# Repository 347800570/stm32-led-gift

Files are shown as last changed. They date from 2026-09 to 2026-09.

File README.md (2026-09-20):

# 基于STM32的灯带礼物制作项目

用木板、可寻址灯带和自己设计的控制板，制作一块能遥控、感知温度、跟随音乐闪动的灯牌。
采用 STM32F042G6U6TR + WS2812B，提供 KiCad 硬件、CubeMX/Keil 固件和基础实验。固件独立运行，不需要 Wi-Fi、手机应用或联网服务，也不是 WLED 固件移植版。

## 能做什么

| 遥控键 | 灯光效果 |
| --- | --- |
| 1 | 整条红橙黄绿蓝靛紫循环渐变 |
| 2 | 暖橙呼吸 |
| 3 | 沿灯珠编号流动的彩虹 |
| 4 | 蓝白流星 |
| 5 | 随机星光 |
| 6 | 根据实际位置，从木板底部向上燃烧的火焰 |
| 7 | 环境冷暖：18°C蓝、25°C绿、32°C红 |
| 8 | 根据声音大小，自下而上点亮的音量柱 |
| 9 | 检测鼓点能量突增，触发整条短暂闪光 |

POWER开关；+/-调整亮度；LEFT/RIGHT在1～7号调速度，在8/9号调声音灵敏度。
关灯时其他键不唤醒，也不修改设置。上电默认3号、15%亮度、速度和灵敏度均为第3档；调整只保存在RAM，断电恢复默认。

## 选择版本

| 固件 | 灯珠数 | 说明 |
| --- | --- | --- |
| [MPLT-67.hex](firmware/MPLT-67.hex) | 67 | 原始布局，27×8空间网格 |
| [SRKL-74.hex](firmware/SRKL-74.hex) | 74 | 新布局，33×12空间网格 |

74颗版本的9种模式已由作者上板验证正常。两套固件均在Windows上用ARMCC5重新编译并进行ARM指令仿真回归；仿真不验证实际电气时序。
首次发行 v0.1.0 为原型参考版本。硬件DRC仍有29项违规，不能把本仓库当作已完成生产审查的设计。

## 快速开始

1. 准备对应控制板、5V WS2812B灯带、NEC红外遥控器、5V电源及USB数据线或SWD下载器。
2. 将灯带DIN接到PB0对应的LED1_DATA，灯带和控制板共地，核对5V极性。
3. 用STM32CubeProgrammer下载对应HEX。SWD连接SWDIO、SWCLK、GND，必要时加NRST；USB DFU操作见[接线与烧录](docs/quick-start.md)。
4. 正常启动时BOOT0为低，复位后应出现彩虹。串口115200、8N1能看到READY日志。
5. 按遥控器1～9逐项验证。空间灯效要求实物排布匹配坐标文件；其他布局须重新编译。

电源按5V设计。Type-C接口并不意味着可以直接使用充电器标称的全部功率；供电能力取决于5V档、线缆、接口及布线。软件最高30%亮度不是闭环电流限制。

## 从哪里开始看

- [接线、下载和遥控使用](docs/quick-start.md)
- [编译、测试与移植布局](docs/development.md)
- [硬件状态与已知问题](docs/hardware.md)
- [基础实验导航](Software/Test/README.md)
- [67颗工程说明](Software/Official%20Version/MPLT_V03/README.md)
- [74颗工程说明](Software/Official%20Version/SRKL_V01/README.md)
- [原理图PDF](Hardware/LED_V01/Schematic.pdf)、[BOM](Hardware/LED_V01/BOM.csv)、[KiCad工程](Hardware/LED_V01/SCH-PCB/LED_V01.kicad_pro)
- [版本记录](CHANGELOG.md)、[贡献说明](CONTRIBUTING.md)、[第三方许可](THIRD_PARTY_NOTICES.md)

## 已知限制

- 使用同一套硬件引脚和指定NEC键码；其他遥控器需要重新学习键码。
- 声控是低频能量突增检测，不是音乐语义识别；拍桌也可能触发，部分音乐会漏检。
- 74颗版RAM静态分配5976/6144 B（含1024 B预留栈），继续增加灯珠或功能前必须重新核算。
- 温度仅用于显示环境冷暖，不承担过温保护。
- PCB为原型资料，DRC未通过；未发布可直接下单的Gerber附件。

## 许可

自有应用代码、测试和文档采用[MIT](LICENSE)；自有硬件设计采用[CERN-OHL-P-2.0](LICENSES/CERN-OHL-P-2.0.txt)。
STM32、CMSIS以及第三方元件库保留各自许可，以上授权不替代第三方许可，范围见[声明](THIRD_PARTY_NOTICES.md)。

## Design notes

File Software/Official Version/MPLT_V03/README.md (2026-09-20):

# MPLT V03：加入麦克风与两个声控模式

## 工程入口

- Keil 工程：`MDK-ARM/MPLT.uvprojx`，目标名 `MPLT`。
- 固件：`MDK-ARM/MPLT/MPLT.hex`；调试文件：`MDK-ARM/MPLT/MPLT.axf`。
- STM32F042G6U6TR，系统时钟 HSI48，48 MHz。
- PB0 / TIM3_CH3 / DMA1_Channel2 控制一条 67 颗 WS2812B 灯带。
- PA3 / EXTI 双边沿接收 NEC 红外，用户码字节为 `00 FF`。
- TIM14 自由运行，1 MHz，每 65.536 ms 回绕，不要在其他模块清零。
- USART1：PB6 TX、PB7 RX，115200、8N1，只输出日志。
- DS18B20：PA2 开漏、外部上拉、独立 VDD 供电；仅支持总线上一颗传感器，不使用寄生供电。
- 麦克风：PA0/ADC_IN0，TIM1 TRGO 8 kHz触发，DMA1_Channel1循环接收。
- 第二路灯带、PA1 实体按键保留基础配置，不启动业务。

## 操作规则

上电开灯，模式 3，亮度 15%，速度第 3 档，声音灵敏度第 3 档。

| 按键 | NEC 键码 | 功能 |
| --- | --- | --- |
| POWER | 0x45 | 开关灯，重新打开时恢复模式和参数 |
| 1 | 0x0C | 整条七色循环，默认保持 1 秒、渐变 1 秒 |
| 2 | 0x18 | 暖橙呼吸，默认一个周期 3 秒 |
| 3 | 0x5E | 流动彩虹，沿 1→67 方向移动 |
| 4 | 0x08 | 蓝白流星，沿 1→67 方向移动 |
| 5 | 0x1C | 暖白星光，随机位置淡入淡出 |
| 6 | 0x5A | 整板空间火焰，从木板底部向上升腾 |
| 7 | 0x42 | 环境温度颜色，18°C蓝、25°C绿、32°C红 |
| 8 | 0x52 | 空间音量柱，按实际高度从下往上点亮，绿→黄→红 |
| 9 | 0x4A | 低频鼓点触发整条闪光脉冲，颜色缓慢循环 |
| + | 0x40 | 增亮 3 个百分点，上限 30% |
| - | 0x19 | 减亮 3 个百分点，下限 3% |
| LEFT | 0x07 | 1～7号减速；8/9号降低声音灵敏度 |
| RIGHT | 0x09 | 1～7号加速；8/9号提高声音灵敏度 |

速度为 0.5、0.75、1、1.5、2 倍。数字键切换后重置动画。
POWER关闭时冻结动画，重新打开后继续；模式、亮度、速度、灵敏度均保留。
采样始终运行，重新打开声控模式时显示当前声音强弱。静音熄灭不等于POWER关机，仍可用数字键切模式。
关灯时所有非 POWER 按键均不改变状态，数字键也不能唤醒。
仅调整键支持长按：至少等待 350 ms，随后相邻调整至少间隔 160 ms；
实际间隔还取决于遥控器重复帧发送周期。POWER、模式键忽略 NEC 重复码。
重复帧距离上一个有效帧超过 180 ms 时不执行。
未分配键只输出提示。断电后全部恢复默认，不写 Flash。
温度模式的颜色只由温度决定，速度键仍改变全局速度设置，但不改变温度采样周期。

## V03 声控功能

### 数据流程

ADC硬件校准 → 启动128点循环DMA → 启动TIM1 → 每64点处理一次 → 去直流。
随后分两路：8号计算音量包络；9号提取低频能量并检测鼓点，触发独立灯光脉冲。

TIM1时钟48 MHz，PSC=47、ARR=124、TRGO=Update，采样周期125 us。
ADC为12位右对齐，DMA两端Half Word；独立缓冲128×2=256 B，每半缓冲64点对应8 ms。
ADC DMA回调只处理64点整数数据，不打印、不等待；红外中断优先级0，ADC DMA优先级1。
从已完成且DMA当前没有写入的半缓冲读取；处理前后核对DMA位置，发现过期数据就丢弃并恢复采样。

直流偏置由低通跟踪，时间常数约32 ms；初值取首个样本，以避免1.65V偏置造成虚假音量。
8号使用去直流后的平均绝对幅度，固定噪声门为 `Core/Inc/audio.h` 的 `AUDIO_NOISE_GATE=12`，不做上电背景噪声学习。
8号亮度每8 ms更新，上升向目标靠近一半，下降向目标靠近十六分之一，最终精确回到0。
9号采用低频能量突增检测，无FFT；不将8号包络或原始音量直接映射为亮度。

### 8号：空间音量柱

声音越大，点亮高度越高。四个字共同使用原来的y坐标，低处绿色、中间黄色、高处红色。
每个高度层独立使用亮灭滞回：超过原点亮阈值才点亮，已点亮后要降到更低的熄灭阈值才熄灭。
默认熄灭阈值比点亮阈值低一层音量跨度的25%；例如y=4层LEVEL达到128点亮，降到119及以下才熄灭。
120～127之间保持之前状态，同高度灯珠同步。临界层点亮后保留至少64/255的效果亮度，再统一乘全局亮度，避免RGB在零附近反复跳动。
亮度变化采用约80 ms满幅过渡；静音/采样故障的LEVEL=0会立即清空滞回状态并全黑，重新进入模式也重置状态。
参数位于 `Core/Inc/effects.h`：`VOLUME_HYSTERESIS_PERCENT`（默认25，允许1～99）、
`VOLUME_HOLD_BRIGHTNESS`（默认64）、`VOLUME_FADE_MS`（默认80）。若实物仍有边界闪烁，可适当增大滞回百分比。
整体仍受3%～30%的全局亮度设置限制。

### 9号：鼓点律动

全部67颗灯珠在检测到低频鼓点后立即达到固定效果峰值，再用150 ms线性渐灭。实际峰值仍受全局亮度限制。
每次触发后150 ms内不重复触发，两个鼓点之间的小幅音量波动不改变已触发的脉冲。
颜色保持12秒缓慢循环，LEFT/RIGHT调整鼓点触发难度，不改变色彩周期或单次脉冲峰值。

滤波器在8 kHz采样下使用一阶约40 Hz高通，串联两个一阶约400 Hz低通，同时保留更多中低频鼓声。
低通系数由37改为69；400 Hz指每个一阶环节，串联后的整体截止频率并非400 Hz，也不是理想带通边界。
能量先做短时平滑，再同时检查绝对门槛、相对近期背景能量的倍数以及能量明显上升。
触发后还要求能量回落再重新允许触发。背景以约256 ms时间尺度持续跟踪，采样启动前128 ms只建立滤波与背景状态。
切换模式清除尚未结束的闪光脉冲，检测器继续跟踪背景。采样故障立即全黑；恢复采样会重新建立背景状态。

参数在 `Core/Inc/beat.h`：`BEAT_REFRACTORY_MS`防重复间隔、`BEAT_PULSE_MS`渐灭时长，默认均为150。
`BEAT_HP_COEFF_Q8`、`BEAT_LP_COEFF_Q8`对应滤波系数，随采样率变化需重新设计。
旧的 `AUDIO_PULSE_RELEASE_DIVISOR` 已移除。
这是一种轻量能量突增检测，真实音乐仍需调试；拍桌、碰撞等低频冲击也可能触发，低频不明显的鼓声可能漏检。

### 灵敏度与噪声门

8/9号共用5档灵敏度，切模式保留、上电默认第3档。1～7号动画速度独立保存。
8号每档满量程交流幅度（已扣除噪声门）为320、200、128、80、48个ADC码值；数值越小越灵敏。
可在 `Core/Src/audio.c` 的 `full_scales` 中修改，8号噪声门在 `audio.h` 中修改。
9号参数在 `Core/Src/beat.c`：绝对门槛 `floors` 为144、100、64、36、16，背景倍数 `ratios` 为3.00、2.50、2.00、1.50、1.00。
保留当前实物调试参数，第5档门槛为背景加16；重新允许触发条件和150 ms时序不变。
能量单位为滤波后ADC码值平方/16；判断门槛为背景乘对应倍数再加绝对门槛，不能将这些数值与AMP直接比较。

建议先用默认参数测试，安静时记录AMP范围，再对照正常说话/音乐时的AMP：

- 8号安静时仍频繁亮灯：将噪声门略调高到安静AMP之上。
- 正常声音很少点亮：按RIGHT提高灵敏度，再考虑调整对应幅度范围。
- 经常满格：按LEFT降低灵敏度。
- CLIP持续较高：检查模拟输入是否接近0V/3.3V，可能需要降低模拟放大倍数；软件灵敏度不会修复模拟削顶。
- 9号误触发时按LEFT降低灵敏度；鼓点漏检时按RIGHT提高，结合LOW、BG及BEATS观察触发效果。

### 日志与故障

串口每秒输出例如 `AUDIO OK AMP=60 LEVEL=96 LEVEL9=80 LOW=140 BG=30 BEATS=4 BIAS=2048 CLIP=0 ERR=0 BLOCKS=125`。

| 字段 | 含义 |
| --- | --- |
| WAITING/OK/FAULT | 等待首块/采样正常/采样故障 |
| AMP | 最新64点去直流后的平均绝对幅度，单位ADC码值，未经噪声门处理 |
| LEVEL | 8号使用的0～255音量包络，故障时0 |
| LEVEL9 | 9号鼓点闪光脉冲的当前亮度，0～255，故障时0 |
| LOW / BG | 当前低频能量 / 背景能量估计 |
| BEATS | 本次采样启动以来检测到的鼓点次数；日志每秒一次，短脉冲可能看不到LEVEL9峰值，可看计数是否增长 |
| BIAS | 直流偏置估计，正常约2048，取决于实际模拟电路 |
| CLIP | 最新一块中小于等于8或大于等于4087的采样数量，范围0～64 |
| ERR | 采样失败/恢复错误累计次数 |
| BLOCKS | 已处理的有效半缓冲块数，正常每秒约增加125 |

超过100 ms没有新数据、ADC溢出、DMA错误或过期半缓冲均使声控输出归零，每秒尝试重新校准并启动采样。
红外和其他灯效继续工作；安静输入本身不会报错。ADC正常采样并不等于麦克风本体正常，持续直流/削顶需结合BIAS、CLIP检查硬件。

#### 鼓点窗口诊断

新增 `BEAT WIN VALID=1 PEAK=100 TH=70 BG=3 SENS=3 HIT=1 BELOW=110 RISE=8 ARM=5 LOCK=1`。
与温度/音频日志错开500 ms输出，正常每秒一次；第一次窗口约1.5秒，采样重启会清空窗口。
峰值与门槛/背景在同一采样块记录，再在主循环短暂关中断取出并清空统计；中断内不打印。

- `VALID`：是否包含预热之后的有效块；为0时本行没有可分析的数据。
- `PEAK`：本窗口最大的平滑低频能量；`TH`、`BG`、`SENS`为出现该峰值时的门槛、背景及灵敏度。
- `HIT`：本窗口触发次数；`BEATS`仍为采样启动以来累计次数。
- `BELOW`：能量没有超过门槛的块数。
- `RISE`：已超过门槛，但相比上一块上升不足的块数。
- `ARM`：已满足门槛及上升条件，但上次触发后能量尚未充分回落的块数。
- `LOCK`：其他条件满足，但距上次触发还不足150 ms的块数。

每块只归入一个结果，按BELOW、RISE、ARM、LOCK的顺序记录首个失败条件，否则计入HIT。
各计数之和正常约125/秒（不含启动预热块）；每项最大65535，避免长时间不取日志时回绕。
这些是采样块统计，不是漏掉的鼓点数量。PEAK对应的块也不一定就是成功触发的块。
调试先保持同一音源、音量和灵敏度，对照PEAK与TH；本次没有降低门槛或改变150 ms时序，8号算法不变。

## 空间火焰与温度模式

### 6号：空间火焰

使用用户确认的 `灯带位置.txt`，与 `Core/Src/led_layout.c` 中的 67 个坐标一一对应。
坐标原点在木板左下方，x=0～26、y=0～7。保留第一个字底部高一行、第四个字竖线对齐65号的原排布。

27×8 热量网格占216 B RAM。底部随机补充热量，向上扩散、逐层冷却；四个字共享同一片热场，
空隙处也计算热量，并非每个字各自燃烧。热量映射为黑、红、橙黄、淡黄白。
中档每40 ms更新一步，LEFT/RIGHT调整火焰速度；1～5号仍按灯珠串联顺序或随机位置显示。

### 7号：环境冷暖

- 18°C及以下为蓝色；25°C为绿色；32°C及以上为红色，区间线性插值。
- 约每秒发起一次转换。首次有效值直接采用，以后每个有效样本向新温度靠近四分之一。
- 转换等待760 ms期间立即返回主循环，不使用 `HAL_Delay(750)`。
- 暂存器分9次任务调用读取，每次读取一字节；校验CRC、配置保留位和-55～125°C范围。
- 不写配置寄存器或EEPROM；兼容9～12位分辨率，屏蔽低分辨率下的未定义低位。
- 上电未收到有效数据时暂不点亮温度颜色。短暂失败保持上次颜色；距离上次有效样本满5秒，显示低亮紫色。
- 有效数据恢复后自动恢复温度颜色。关灯和其他模式下也持续测温，所以切换到7号无需重新等待。
- 只表示环境冷暖，不承担过温保护。

每秒串口输出例如 `TEMP OK LAST=25.00C SAMPLES=12`。
`LAST` 是最新成功读取的温度，不是经过平滑的显示值；读取失败时可能保留旧值。
状态包括 `WAITING`、`OK`、`NO_DEVICE`、`CRC_ERROR`、`BAD_DATA`、`NOT_READY`；超时另附 `FAULT`。

### 与红外共存

TIM14由 `IR_Init()` 启动，温度延时只计算时间差、不清零计数器。
复位低电平480 us期间保持中断开放；仅存在脉冲采样和读写位的关键窗口短暂屏蔽中断。
最长计划延时窗口为70 us，另有少量指令开销；不再将整个复位过程近1 ms都关中断。
各窗口恢复调用前的PRIMASK；实际板上仍需验证温度采样期间连续遥控是否可靠。

## 代码阅读顺序

1. `Core/Src/main.c`：CubeMX 初始化后调用 `App_Init()`，主循环调用 `App_Task()`。
2. `Core/Src/app.c`：先取红外事件并更新状态，再按约 20 ms 周期生成和发送画面。
3. `Core/Src/ir.c`：边沿间隔驱动 NEC 状态机，完整校验后放入事件队列；中断里不打印日志。
4. `Core/Src/effects.c`：根据模式、速度、经过时间，生成不含全局亮度缩放的 RGB 数组。
5. `Core/Src/led.c`：限制亮度，编码为 GRB、高位先发，DMA 异步输出。
6. `Core/Src/debug_log.c`：主循环检查 TXE，非阻塞发送日志。不要同时用其他 UART 发送函数操作 USART1。
7. `Core/Src/temperature.c`：发起转换、等待、分段读暂存器、校验及平滑。
8. `Core/Src/led_layout.c`：67颗灯珠的只读空间坐标，存放在Flash。
9. `Core/Src/audio.c`：ADC启动/恢复、DMA半缓冲处理、声音幅度和平滑包络。
10. `Core/Src/beat.c`：低频滤波、能量突增检测、防重复触发和独立灯光脉冲。

灯带发送期间不修改 DMA 缓冲。发送完成回调停止 DMA；异常或超过 20 ms 未完成时停止并重试。
关灯请求保留到黑帧成功提交，即使上一帧正在发送也不会丢失。
DMA 缓冲为 1866 B：2 个前导零 + 67×24 数据位 + 256 个复位零。
末尾低电平约 320 us，帧间另留至少一个 HAL tick。
效果和日志没有使用长时间阻塞延时、动态内存或浮点运算。

## CubeMX 与工程维护

自定义代码位于独立文件，main.c 的调用位于 USER CODE 区域。
Keil 的 `MPLT Application` 分组包含 app、led、effects、ir、debug_log、temperature、led_layout、audio、beat 九个源文件。
若再次生成 CubeMX 工程，请检查该分组仍在，否则手动重新加入这些文件。
灯珠数量集中在 `Core/Inc/led.h` 的 `LED_COUNT`；空间映射固定为67颗，修改数量必须同步修改坐标并检查RAM和发送时间。
V03将CubeMX HeapSize及启动文件Heap_Size同步改为0，保留StackSize=0x400。后续不要直接引入malloc/calloc/realloc或依赖堆的库。
星光和火焰在union中共用216 B工作区，切模式清零、星光按需初始化；麦克风缓冲始终独立，不能与效果共用。
30% 是软件亮度缩放上限，不是闭环电流限制。

## 编译与逻辑验证

2026-09-10，Keil ARMCC 5.06：0 Error、0 Warning。

- Code：18664 B；RO-data：964 B；RW-data：228 B；ZI-data：5372 B。
- Flash 装载量：19856 B / 32768 B。
- RAM分配：5600 B / 6144 B，剩余544 B。
- 上述RAM包含1024 B栈和256 B麦克风DMA缓冲；堆预留为0。
- 链接器静态调用图给出最大已知调用链栈 176 B，但含未知路径，不能替代运行时栈验证。

`Tests/test_firmware.py` 使用 Unicorn 执行实际生成的 ARM 函数，模拟 HAL 外设边界。
依赖 `unicorn`、`pyelftools`；重新编译后依次执行 `python Tests/test_firmware.py`、`python Tests/test_v02.py`、`python Tests/test_v03.py`、`python Tests/test_beat.py`。
已覆盖五种模式切换、关灯忽略按键、DMA 忙时关灯、亮度速度边界、长按过滤、
失效重复帧、错误 NEC 校验、灯效变化、七色时间、GRB 编码、亮度硬上限、复位位和超时恢复。
测试没有模拟真实电气信号、DMA 总线竞争或中断时延。
V02新增覆盖：带符号温度及分辨率、CRC、采样等待、无设备、无效数据、转换未完成、超时紫色与恢复，
以及1-Wire临界区的PRIMASK恢复、67颗灯珠逐项坐标核对、火焰从低处向高处推进、6/7号按键。
仿真器按ELF节的运行地址初始化RAM，包含实际随机种子，避免省略启动代码造成假结果。
V03新增覆盖：校准/ADC/TIM1启动顺序、直流与底噪抑制、幅度响应、5档灵敏度、快速上升慢回落、削顶诊断、
ADC过期/DMA错误/重启失败恢复、时间戳中断竞争、音量柱配色与临界层滞回/渐亮、整条跃动、独立灵敏度设置和共用工作区复位。
滞回测试覆盖阈值上下反复波动、保持亮度在3%全局亮度下仍可见、低阈值熄灭、同高度同步、静音和重新进入模式清除状态。
鼓点测试以实际ARM代码处理合成ADC信号，覆盖低幅噪声、高频信号、连续底鼓、持续低频音、固定峰值、150 ms渐灭和防重复触发、弱鼓点灵敏度及模式重置。
回归测试验证8号保持原包络和滞回，9号读取独立脉冲，故障全黑。合成信号测试不能代替真实音乐识别率或中断时延测量。
本次新增覆盖300 Hz合成鼓声触发、峰值与同时刻门槛/背景配对、窗口分类总数和读取清零。

## 上板验证顺序

1. 打开上述 Keil 工程编译并烧录。若使用 USB DFU，HEX 自带地址；下载后将 BOOT0 恢复正常启动并复位。
2. 串口设115200、8N1，应看到 `MPLT V03 READY`，模式3、15%亮度、SPEED=3、SENS=3；灯带显示流动彩虹。
3. 逐个按 1～5，核对五种效果；按 +、-、LEFT、RIGHT，核对方向及上限下限。
4. 长按 POWER，确认只开关一次；长按数字键，确认动画不会反复重置。
5. 长按 +、-、LEFT、RIGHT，确认重复调节及限幅。
6. 关灯后按1～9和调节键，应保持熄灭；POWER再开应恢复之前状态。
7. 开灯时按MENU、0等未分配键，应显示 `UNASSIGNED IN V03`，画面不切换。
8. 断电重启，恢复模式 3、15% 亮度、中档速度。
9. 连续切换和长按测试，观察是否出现 `LED DMA ERROR` 或大量 `IR INVALID/OVERFLOW`。
10. 按6号，确认四个字共同从木板底部向上燃烧；LEFT/RIGHT应改变火焰速度。
11. 按7号，查看串口温度与颜色对应；用手握住探头缓慢加温，颜色应逐渐向红色方向变化。
12. 断开传感器信号后短时保留颜色，最后一次成功读取满5秒后变低亮紫色；重新接回后自动恢复。
13. 测温过程中持续按键和长按调节，确认不会由于测温丢失大量红外指令。
14. 按8号，说话或播放音乐，确认从下往上显示音量，边界层渐亮；安静后逐渐全黑。
15. 按9号播放底鼓清晰的音乐，确认每次鼓点触发全条短脉冲、颜色缓慢变化；鼓点间隙不应跟随噪声持续抖动。
16. 在8/9号中用LEFT/RIGHT调整SENS，确认范围1～5且两个模式共用；切回3号后LEFT/RIGHT仍改变SPEED。
17. 连续运行并切换5、6、7、8、9号，观察BLOCKS持续增加、ERR不增长，同时确认温度和红外正常。
18. 8号模式下保持临界大小的声音，观察同高度灯珠不再因小幅音量波动反复亮灭；逐渐降低声音，确认降得更低才熄灭。效果仍需实物验证。

若串口有正常按键日志但灯带不亮，优先检查数据接到 PB0 对应的 LED1_DATA、灯带 DIN 方向、5V 与共地。
本版本已完成编译和逻辑测试，实物烧录与示波器验证待执行。

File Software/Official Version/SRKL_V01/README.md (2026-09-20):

# SRKL V01：74颗灯珠空间布局移植

## 工程入口

- Keil 工程：`MDK-ARM/MPLT.uvprojx`，目标名 `MPLT`。
- 固件：`MDK-ARM/MPLT/SRKL.hex`；调试文件：`MDK-ARM/MPLT/SRKL.axf`。目录中旧的MPLT.hex不是本次移植产物。
- STM32F042G6U6TR，系统时钟 HSI48，48 MHz。
- PB0 / TIM3_CH3 / DMA1_Channel2 控制一条 74 颗 WS2812B 灯带。
- PA3 / EXTI 双边沿接收 NEC 红外，用户码字节为 `00 FF`。
- TIM14 自由运行，1 MHz，每 65.536 ms 回绕，不要在其他模块清零。
- USART1：PB6 TX、PB7 RX，115200、8N1，只输出日志。
- DS18B20：PA2 开漏、外部上拉、独立 VDD 供电；仅支持总线上一颗传感器，不使用寄生供电。
- 麦克风：PA0/ADC_IN0，TIM1 TRGO 8 kHz触发，DMA1_Channel1循环接收。
- 第二路灯带、PA1 实体按键保留基础配置，不启动业务。

## 操作规则

上电开灯，模式 3，亮度 15%，速度第 3 档，声音灵敏度第 3 档。

| 按键 | NEC 键码 | 功能 |
| --- | --- | --- |
| POWER | 0x45 | 开关灯，重新打开时恢复模式和参数 |
| 1 | 0x0C | 整条七色循环，默认保持 1 秒、渐变 1 秒 |
| 2 | 0x18 | 暖橙呼吸，默认一个周期 3 秒 |
| 3 | 0x5E | 流动彩虹，沿 1→74 方向移动 |
| 4 | 0x08 | 蓝白流星，沿 1→74 方向移动 |
| 5 | 0x1C | 暖白星光，随机位置淡入淡出 |
| 6 | 0x5A | 整板空间火焰，从木板底部向上升腾 |
| 7 | 0x42 | 环境温度颜色，18°C蓝、25°C绿、32°C红 |
| 8 | 0x52 | 空间音量柱，按实际高度从下往上点亮，绿→黄→红 |
| 9 | 0x4A | 低频鼓点触发整条闪光脉冲，颜色缓慢循环 |
| + | 0x40 | 增亮 3 个百分点，上限 30% |
| - | 0x19 | 减亮 3 个百分点，下限 3% |
| LEFT | 0x07 | 1～7号减速；8/9号降低声音灵敏度 |
| RIGHT | 0x09 | 1～7号加速；8/9号提高声音灵敏度 |

速度为 0.5、0.75、1、1.5、2 倍。数字键切换后重置动画。
POWER关闭时冻结动画，重新打开后继续；模式、亮度、速度、灵敏度均保留。
采样始终运行，重新打开声控模式时显示当前声音强弱。静音熄灭不等于POWER关机，仍可用数字键切模式。
关灯时所有非 POWER 按键均不改变状态，数字键也不能唤醒。
仅调整键支持长按：至少等待 350 ms，随后相邻调整至少间隔 160 ms；
实际间隔还取决于遥控器重复帧发送周期。POWER、模式键忽略 NEC 重复码。
重复帧距离上一个有效帧超过 180 ms 时不执行。
未分配键只输出提示。断电后全部恢复默认，不写 Flash。
温度模式的颜色只由温度决定，速度键仍改变全局速度设置，但不改变温度采样周期。

## V03 声控功能

### 数据流程

ADC硬件校准 → 启动128点循环DMA → 启动TIM1 → 每64点处理一次 → 去直流。
随后分两路：8号计算音量包络；9号提取低频能量并检测鼓点，触发独立灯光脉冲。

TIM1时钟48 MHz，PSC=47、ARR=124、TRGO=Update，采样周期125 us。
ADC为12位右对齐，DMA两端Half Word；独立缓冲128×2=256 B，每半缓冲64点对应8 ms。
ADC DMA回调只处理64点整数数据，不打印、不等待；红外中断优先级0，ADC DMA优先级1。
从已完成且DMA当前没有写入的半缓冲读取；处理前后核对DMA位置，发现过期数据就丢弃并恢复采样。

直流偏置由低通跟踪，时间常数约32 ms；初值取首个样本，以避免1.65V偏置造成虚假音量。
8号使用去直流后的平均绝对幅度，固定噪声门为 `Core/Inc/audio.h` 的 `AUDIO_NOISE_GATE=12`，不做上电背景噪声学习。
8号亮度每8 ms更新，上升向目标靠近一半，下降向目标靠近十六分之一，最终精确回到0。
9号采用低频能量突增检测，无FFT；不将8号包络或原始音量直接映射为亮度。

### 8号：空间音量柱

声音越大，点亮高度越高。四个字共同使用原来的y坐标，低处绿色、中间黄色、高处红色。
每个高度层独立使用亮灭滞回：超过原点亮阈值才点亮，已点亮后要降到更低的熄灭阈值才熄灭。
默认熄灭阈值比点亮阈值低一层音量跨度的25%；例如y=6层LEVEL达到128点亮，降到122及以下才熄灭。
123～127之间保持之前状态，同高度灯珠同步。临界层点亮后保留至少64/255的效果亮度，再统一乘全局亮度，避免RGB在零附近反复跳动。
亮度变化采用约80 ms满幅过渡；静音/采样故障的LEVEL=0会立即清空滞回状态并全黑，重新进入模式也重置状态。
参数位于 `Core/Inc/effects.h`：`VOLUME_HYSTERESIS_PERCENT`（默认25，允许1～99）、
`VOLUME_HOLD_BRIGHTNESS`（默认64）、`VOLUME_FADE_MS`（默认80）。若实物仍有边界闪烁，可适当增大滞回百分比。
整体仍受3%～30%的全局亮度设置限制。

### 9号：鼓点律动

全部74颗灯珠在检测到低频鼓点后立即达到固定效果峰值，再用150 ms线性渐灭。实际峰值仍受全局亮度限制。
每次触发后150 ms内不重复触发，两个鼓点之间的小幅音量波动不改变已触发的脉冲。
颜色保持12秒缓慢循环，LEFT/RIGHT调整鼓点触发难度，不改变色彩周期或单次脉冲峰值。

滤波器在8 kHz采样下使用一阶约40 Hz高通，串联两个一阶约400 Hz低通，同时保留更多中低频鼓声。
低通系数由37改为69；400 Hz指每个一阶环节，串联后的整体截止频率并非400 Hz，也不是理想带通边界。
能量先做短时平滑，再同时检查绝对门槛、相对近期背景能量的倍数以及能量明显上升。
触发后还要求能量回落再重新允许触发。背景以约256 ms时间尺度持续跟踪，采样启动前128 ms只建立滤波与背景状态。
切换模式清除尚未结束的闪光脉冲，检测器继续跟踪背景。采样故障立即全黑；恢复采样会重新建立背景状态。

参数在 `Core/Inc/beat.h`：`BEAT_REFRACTORY_MS`防重复间隔、`BEAT_PULSE_MS`渐灭时长，默认均为150。
`BEAT_HP_COEFF_Q8`、`BEAT_LP_COEFF_Q8`对应滤波系数，随采样率变化需重新设计。
旧的 `AUDIO_PULSE_RELEASE_DIVISOR` 已移除。
这是一种轻量能量突增检测，真实音乐仍需调试；拍桌、碰撞等低频冲击也可能触发，低频不明显的鼓声可能漏检。

### 灵敏度与噪声门

8/9号共用5档灵敏度，切模式保留、上电默认第3档。1～7号动画速度独立保存。
8号每档满量程交流幅度（已扣除噪声门）为320、200、128、80、48个ADC码值；数值越小越灵敏。
可在 `Core/Src/audio.c` 的 `full_scales` 中修改，8号噪声门在 `audio.h` 中修改。
9号参数在 `Core/Src/beat.c`：绝对门槛 `floors` 为144、100、64、36、16，背景倍数 `ratios` 为3.00、2.50、2.00、1.50、1.00。
保留移植时MPLT_V03及目标工程中现有的调试参数：第5档门槛为背景加16，未回退到此前说明中的1.60倍；重新允许触发条件和150 ms时序不变。
能量单位为滤波后ADC码值平方/16；判断门槛为背景乘对应倍数再加绝对门槛，不能将这些数值与AMP直接比较。

建议先用默认参数测试，安静时记录AMP范围，再对照正常说话/音乐时的AMP：

- 8号安静时仍频繁亮灯：将噪声门略调高到安静AMP之上。
- 正常声音很少点亮：按RIGHT提高灵敏度，再考虑调整对应幅度范围。
- 经常满格：按LEFT降低灵敏度。
- CLIP持续较高：检查模拟输入是否接近0V/3.3V，可能需要降低模拟放大倍数；软件灵敏度不会修复模拟削顶。
- 9号误触发时按LEFT降低灵敏度；鼓点漏检时按RIGHT提高，结合LOW、BG及BEATS观察触发效果。

### 日志与故障

串口每秒输出例如 `AUDIO OK AMP=60 LEVEL=96 LEVEL9=80 LOW=140 BG=30 BEATS=4 BIAS=2048 CLIP=0 ERR=0 BLOCKS=125`。

| 字段 | 含义 |
| --- | --- |
| WAITING/OK/FAULT | 等待首块/采样正常/采样故障 |
| AMP | 最新64点去直流后的平均绝对幅度，单位ADC码值，未经噪声门处理 |
| LEVEL | 8号使用的0～255音量包络，故障时0 |
| LEVEL9 | 9号鼓点闪光脉冲的当前亮度，0～255，故障时0 |
| LOW / BG | 当前低频能量 / 背景能量估计 |
| BEATS | 本次采样启动以来检测到的鼓点次数；日志每秒一次，短脉冲可能看不到LEVEL9峰值，可看计数是否增长 |
| BIAS | 直流偏置估计，正常约2048，取决于实际模拟电路 |
| CLIP | 最新一块中小于等于8或大于等于4087的采样数量，范围0～64 |
| ERR | 采样失败/恢复错误累计次数 |
| BLOCKS | 已处理的有效半缓冲块数，正常每秒约增加125 |

超过100 ms没有新数据、ADC溢出、DMA错误或过期半缓冲均使声控输出归零，每秒尝试重新校准并启动采样。
红外和其他灯效继续工作；安静输入本身不会报错。ADC正常采样并不等于麦克风本体正常，持续直流/削顶需结合BIAS、CLIP检查硬件。

#### 鼓点窗口诊断

新增 `BEAT WIN VALID=1 PEAK=100 TH=70 BG=3 SENS=3 HIT=1 BELOW=110 RISE=8 ARM=5 LOCK=1`。
与温度/音频日志错开500 ms输出，正常每秒一次；第一次窗口约1.5秒，采样重启会清空窗口。
峰值与门槛/背景在同一采样块记录，再在主循环短暂关中断取出并清空统计；中断内不打印。

- `VALID`：是否包含预热之后的有效块；为0时本行没有可分析的数据。
- `PEAK`：本窗口最大的平滑低频能量；`TH`、`BG`、`SENS`为出现该峰值时的门槛、背景及灵敏度。
- `HIT`：本窗口触发次数；`BEATS`仍为采样启动以来累计次数。
- `BELOW`：能量没有超过门槛的块数。
- `RISE`：已超过门槛，但相比上一块上升不足的块数。
- `ARM`：已满足门槛及上升条件，但上次触发后能量尚未充分回落的块数。
- `LOCK`：其他条件满足，但距上次触发还不足150 ms的块数。

每块只归入一个结果，按BELOW、RISE、ARM、LOCK的顺序记录首个失败条件，否则计入HIT。
各计数之和正常约125/秒（不含启动预热块）；每项最大65535，避免长时间不取日志时回绕。
这些是采样块统计，不是漏掉的鼓点数量。PEAK对应的块也不一定就是成功触发的块。
调试先保持同一音源、音量和灵敏度，对照PEAK与TH；本次没有降低门槛或改变150 ms时序，8号算法不变。

## 空间火焰与温度模式

### 6号：空间火焰

使用用户确认的 `灯带位置.txt`，与 `Core/Src/led_layout.c` 中的 74 个坐标一一对应。
坐标原点在木板左下方，x=0～32、y=0～11。按新TXT的制表符列和行保留空隙；忽略顶部空行，底部为y=0。

33×12 热量网格占396 B RAM。底部随机补充热量，向上扩散、逐层冷却；四个字共享同一片热场，
空隙处也计算热量，并非每个字各自燃烧。热量映射为黑、红、橙黄、淡黄白。
中档每40 ms更新一步，LEFT/RIGHT调整火焰速度；1～5号仍按灯珠串联顺序或随机位置显示。

### 7号：环境冷暖

- 18°C及以下为蓝色；25°C为绿色；32°C及以上为红色，区间线性插值。
- 约每秒发起一次转换。首次有效值直接采用，以后每个有效样本向新温度靠近四分之一。
- 转换等待760 ms期间立即返回主循环，不使用 `HAL_Delay(750)`。
- 暂存器分9次任务调用读取，每次读取一字节；校验CRC、配置保留位和-55～125°C范围。
- 不写配置寄存器或EEPROM；兼容9～12位分辨率，屏蔽低分辨率下的未定义低位。
- 上电未收到有效数据时暂不点亮温度颜色。短暂失败保持上次颜色；距离上次有效样本满5秒，显示低亮紫色。
- 有效数据恢复后自动恢复温度颜色。关灯和其他模式下也持续测温，所以切换到7号无需重新等待。
- 只表示环境冷暖，不承担过温保护。

每秒串口输出例如 `TEMP OK LAST=25.00C SAMPLES=12`。
`LAST` 是最新成功读取的温度，不是经过平滑的显示值；读取失败时可能保留旧值。
状态包括 `WAITING`、`OK`、`NO_DEVICE`、`CRC_ERROR`、`BAD_DATA`、`NOT_READY`；超时另附 `FAULT`。

### 与红外共存

TIM14由 `IR_Init()` 启动，温度延时只计算时间差、不清零计数器。
复位低电平480 us期间保持中断开放；仅存在脉冲采样和读写位的关键窗口短暂屏蔽中断。
最长计划延时窗口为70 us，另有少量指令开销；不再将整个复位过程近1 ms都关中断。
各窗口恢复调用前的PRIMASK；实际板上仍需验证温度采样期间连续遥控是否可靠。

## 代码阅读顺序

1. `Core/Src/main.c`：CubeMX 初始化后调用 `App_Init()`，主循环调用 `App_Task()`。
2. `Core/Src/app.c`：先取红外事件并更新状态，再按约 20 ms 周期生成和发送画面。
3. `Core/Src/ir.c`：边沿间隔驱动 NEC 状态机，完整校验后放入事件队列；中断里不打印日志。
4. `Core/Src/effects.c`：根据模式、速度、经过时间，生成不含全局亮度缩放的 RGB 数组。
5. `Core/Src/led.c`：限制亮度，编码为 GRB、高位先发，DMA 异步输出。
6. `Core/Src/debug_log.c`：主循环检查 TXE，非阻塞发送日志。不要同时用其他 UART 发送函数操作 USART1。
7. `Core/Src/temperature.c`：发起转换、等待、分段读暂存器、校验及平滑。
8. `Core/Src/led_layout.c`：74颗灯珠的只读空间坐标，存放在Flash。
9. `Core/Src/audio.c`：ADC启动/恢复、DMA半缓冲处理、声音幅度和平滑包络。
10. `Core/Src/beat.c`：低频滤波、能量突增检测、防重复触发和独立灯光脉冲。

灯带发送期间不修改 DMA 缓冲。发送完成回调停止 DMA；异常或超过 20 ms 未完成时停止并重试。
关灯请求保留到黑帧成功提交，即使上一帧正在发送也不会丢失。
DMA 缓冲为 2034 B：2 个前导零 + 74×24 数据位 + 256 个复位零。
末尾低电平约 320 us，帧间另留至少一个 HAL tick。
效果和日志没有使用长时间阻塞延时、动态内存或浮点运算。

## CubeMX 与工程维护

自定义代码位于独立文件，main.c 的调用位于 USER CODE 区域。
Keil 的 `SRKL Application` 分组包含 app、led、effects、ir、debug_log、temperature、led_layout、audio、beat 九个源文件。
若再次生成 CubeMX 工程，请检查该分组仍在，否则手动重新加入这些文件。
灯珠数量集中在 `Core/Inc/led.h` 的 `LED_COUNT`；空间映射固定为74颗，修改数量必须同步修改坐标并检查RAM和发送时间。
V03将CubeMX HeapSize及启动文件Heap_Size同步改为0，保留StackSize=0x400。后续不要直接引入malloc/calloc/realloc或依赖堆的库。
星光和火焰在union中共用396 B工作区，切模式清零、星光按需初始化；麦克风缓冲始终独立，不能与效果共用。
30% 是软件亮度缩放上限，不是闭环电流限制。

## 编译与逻辑验证

2026-09-12，Keil ARMCC 5.06：0 Error、0 Warning。

- Code：18696 B；RO-data：976 B；RW-data：212 B；ZI-data：5764 B。
- Flash 装载量：19884 B / 32768 B。
- RAM分配：5976 B / 6144 B，剩余168 B。
- 上述RAM包含1024 B栈和256 B麦克风DMA缓冲；堆预留为0。
- 链接器静态调用图给出最大已知调用链栈 176 B，但含未知路径，不能替代运行时栈验证。

`Tests/test_firmware.py` 使用 Unicorn 执行实际生成的 ARM 函数，模拟 HAL 外设边界。
依赖 `unicorn`、`pyelftools`；重新编译后依次执行 `python Tests/test_firmware.py`、`python Tests/test_v02.py`、`python Tests/test_v03.py`、`python Tests/test_beat.py`。
已覆盖五种模式切换、关灯忽略按键、DMA 忙时关灯、亮度速度边界、长按过滤、
失效重复帧、错误 NEC 校验、灯效变化、七色时间、GRB 编码、亮度硬上限、复位位和超时恢复。
测试没有模拟真实电气信号、DMA 总线竞争或中断时延。
V02新增覆盖：带符号温度及分辨率、CRC、采样等待、无设备、无效数据、转换未完成、超时紫色与恢复，
以及1-Wire临界区的PRIMASK恢复、74颗灯珠逐项坐标核对、火焰从低处向高处推进、6/7号按键。
仿真器按ELF节的运行地址初始化RAM，包含实际随机种子，避免省略启动代码造成假结果。
V03新增覆盖：校准/ADC/TIM1启动顺序、直流与底噪抑制、幅度响应、5档灵敏度、快速上升慢回落、削顶诊断、
ADC过期/DMA错误/重启失败恢复、时间戳中断竞争、音量柱配色与临界层滞回/渐亮、整条跃动、独立灵敏度设置和共用工作区复位。
滞回测试覆盖阈值上下反复波动、保持亮度在3%全局亮度下仍可见、低阈值熄灭、同高度同步、静音和重新进入模式清除状态。
鼓点测试以实际ARM代码处理合成ADC信号，覆盖低幅噪声、高频信号、连续底鼓、持续低频音、固定峰值、150 ms渐灭和防重复触发、弱鼓点灵敏度及模式重置。
回归测试验证8号保持原包络和滞回，9号读取独立脉冲，故障全黑。合成信号测试不能代替真实音乐识别率或中断时延测量。
本次新增覆盖300 Hz合成鼓声触发、峰值与同时刻门槛/背景配对、窗口分类总数和读取清零。

## 上板验证顺序

1. 打开上述 Keil 工程编译并烧录。若使用 USB DFU，HEX 自带地址；下载后将 BOOT0 恢复正常启动并复位。
2. 串口设115200、8N1，应看到 `SRKL V01 READY`，模式3、15%亮度、SPEED=3、SENS=3；灯带显示流动彩虹。
3. 逐个按 1～5，核对五种效果；按 +、-、LEFT、RIGHT，核对方向及上限下限。
4. 长按 POWER，确认只开关一次；长按数字键，确认动画不会反复重置。
5. 长按 +、-、LEFT、RIGHT，确认重复调节及限幅。
6. 关灯后按1～9和调节键，应保持熄灭；POWER再开应恢复之前状态。
7. 开灯时按MENU、0等未分配键，应显示 `UNASSIGNED IN SRKL V01`，画面不切换。
8. 断电重启，恢复模式 3、15% 亮度、中档速度。
9. 连续切换和长按测试，观察是否出现 `LED DMA ERROR` 或大量 `IR INVALID/OVERFLOW`。
10. 按6号，确认四个字共同从木板底部向上燃烧；LEFT/RIGHT应改变火焰速度。
11. 按7号，查看串口温度与颜色对应；用手握住探头缓慢加温，颜色应逐渐向红色方向变化。
12. 断开传感器信号后短时保留颜色，最后一次成功读取满5秒后变低亮紫色；重新接回后自动恢复。
13. 测温过程中持续按键和长按调节，确认不会由于测温丢失大量红外指令。
14. 按8号，说话或播放音乐，确认从下往上显示音量，边界层渐亮；安静后逐渐全黑。
15. 按9号播放底鼓清晰的音乐，确认每次鼓点触发全条短脉冲、颜色缓慢变化；鼓点间隙不应跟随噪声持续抖动。
16. 在8/9号中用LEFT/RIGHT调整SENS，确认范围1～5且两个模式共用；切回3号后LEFT/RIGHT仍改变SPEED。
17. 连续运行并切换5、6、7、8、9号，观察BLOCKS持续增加、ERR不增长，同时确认温度和红外正常。
18. 8号模式下保持临界大小的声音，观察同高度灯珠不再因小幅音量波动反复亮灭；逐渐降低声音，确认降得更低才熄灭。效果仍需实物验证。

若串口有正常按键日志但灯带不亮，优先检查数据接到 PB0 对应的 LED1_DATA、灯带 DIN 方向、5V 与共地。
本版本已完成编译和逻辑测试，实物烧录与示波器验证待执行。

## SRKL移植说明

硬件接线和遥控器沿用MPLT_V03，PB0驱动74颗；9种模式、当前鼓点第5档1.00倍门槛、上电默认第3档均保留。
火焰每层冷却按7/11缩放，补偿高度从8行增加到12行；整板仍共享一片火焰。
Keil入口保留 `MDK-ARM/MPLT.uvprojx` 和MPLT构建目标以兼容现有RTE配置，输出为 `MDK-ARM/MPLT/SRKL.hex`、`SRKL.axf`。
CubeMX文件为 `SRKL.ioc`，重新生成后可能产生新的SRKL Keil工程，需要核对自定义源文件分组。

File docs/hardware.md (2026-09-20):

# 硬件原型与生产边界

源文件位于Hardware/LED_V01/SCH-PCB，配套的Library仅提供本设计使用的元件。
符号从当前原理图嵌入缓存导出，封装从实际引用库收集，库表使用KIPRJMOD相对路径。
可选3D模型引用已移除，因此3D视图可能缺少器件模型；这不影响2D原理图和PCB铜层。

2026-09-15使用KiCad9检查：29项DRC违规、0个未连接焊盘。详见同目录DRC.txt。
主要问题包括USB固定孔的PTH孔环/缺铜、默认0.2mm规则下的细间距焊盘违规、丝印覆盖及一个Logo封装与库不一致。
本次发行不擅自改变经过实物使用的PCB铜层，也不通过放松DRC规则制造通过结果。

原理图PDF和BOM从当前文件重新导出；BOM表示设计记录，不代表库存、替代料或生产审核已完成。
旧个人目录中的Gerber早于当前PCB文件，未收录。当前版本不提供直接下单附件：生产前需结合器件手册、实际封装及板厂能力逐项解决DRC，再重新导出Gerber/钻孔文件。

74颗固件9种模式实物正常，不等于所有生产规则或不同USB主机都验证通过。
木板结构、扩散硅胶和导线固定方式由制作者自行安排；焊盘、灯带和电源回路的载流能力需按实际长度和负载核算。

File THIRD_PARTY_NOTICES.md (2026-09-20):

# 许可范围与第三方声明

根目录MIT仅适用于作者自有应用代码、测试、脚本和文档，不重新许可下列第三方文件。

| 内容 | 来源与许可 |
| --- | --- |
| STM32F0 HAL | STM32CubeF0 1.11.6，BSD-3-Clause，见ThirdParty/STM32CubeF0/Drivers/STM32F0xx_HAL_Driver/LICENSE.txt |
| CMSIS内核头文件 | ARM，Apache-2.0，见ThirdParty/STM32CubeF0/Drivers/CMSIS/LICENSE.txt |
| STM32F0 CMSIS Device | ST/ARM，依组件随附许可及STM32CubeF0 Package_license.md；保留各文件声明 |
| CubeMX生成文件及启动代码 | 保留ST/ARM版权头；按随包Package_license.md及相应组件许可，非作者单独MIT授权 |
| KiCad标准Fuse封装、Device/power符号 | KiCad库，CC-BY-SA-4.0及库例外，见LICENSES/KiCad-library-exception.txt |
| 自有PCB、原理图及作者元件设计 | CERN-OHL-P-2.0；第三方图形/元件内容保留原权利 |

硬件库仅随设计提供使用到的符号和封装，含作者Aboka库及现有Locator/easyeda转换器件资料；不宣称取得器件商标或外观的独占权。
KiCad库例外使引用这些库元素的电路设计无需整体改用CC-BY-SA，但库本身修改/分发仍应遵守相应条款。

未包含WLED或其他调研项目源码；本项目不依赖它们运行。Keil编译器、CubeMX和器件包不包含在仓库内，请按各自条款获取。

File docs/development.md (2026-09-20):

# 开发、测试与维护

## 环境

- Windows、Keil MDK，ARM Compiler 5.06 update 6；此版本未验证ARMClang6或GCC迁移。
- Keil器件包Keil.STM32F0xx_DFP 3.1.1、ARM.CMSIS 6.1.0。
- 可选STM32CubeMX及STM32CubeF0 1.11.6，编辑外设配置时使用。
- KiCad 9用于硬件编辑和导出。
- Python 3、unicorn、pyelftools用于软件逻辑测试。

## 编译

用Keil打开 `Software/Official Version/MPLT_V03/MDK-ARM/MPLT.uvprojx` 或 `Software/Official Version/SRKL_V01/MDK-ARM/MPLT.uvprojx`，选择MPLT目标并编译。
驱动源码随仓库放在ThirdParty/STM32CubeF0，工程使用相对路径；Keil工具链和器件包需要自行合法安装。
输出分别在工程内 `MDK-ARM/MPLT/MPLT.hex` 和 `MDK-ARM/MPLT/SRKL.hex`。不要混用两种布局固件。
预生成固件在仓库firmware目录，仅在重新构建、测试后更新，并运行 `python scripts/check_release.py` 核验。

修改CubeMX配置后注意重新添加自定义源文件分组，保留USER CODE调用；CubeMX可能恢复驱动的本机路径，需要重新改为ThirdParty相对路径。

## 仿真测试

在仓库根目录执行：

    python -m pip install -r requirements-test.txt
    python scripts/test_all.py

必须先编译两套正式工程，测试读取新生成的AXF，不读取firmware里的HEX。
测试覆盖遥控、关灯、DMA编码与恢复、温度、所有灯珠坐标、火焰传播、音量柱滞回及鼓点检测。
仿真只执行ARM函数并模拟HAL边界，不代表真实中断延迟、供电和USB电气兼容性已验证。

## 修改灯珠排布

1. 编辑对应工程的灯带位置.txt。每个制表符单元表示一列，行代表高度；编号连续且不重复。
2. 同步修改Core/Inc/led.h中的LED_COUNT、led_layout.h中的宽高，以及Core/Src/led_layout.c的坐标；数组下标为编号减一，底部y=0。
3. 调整火焰总冷却和测试中的布局预期。只改LED_COUNT不够，火焰和音量柱都依赖空间映射。
4. 编译核算RAM；6KB包含静态数据和栈。默认堆为0，不要未经评估加入动态内存。
5. 上板先用低亮度检查末端灯珠，再测试6/8号方向和9号声控。

## 后续维护

GitHub仓库及其本地检出目录是发布版本的维护入口。原个人实验目录不会自动同步；在其上做的新实验应有选择地移入本仓库，再提交测试结果。
自定义代码优先放在app、effects、led、audio、beat等模块；CubeMX生成区域不要直接手写业务逻辑。
每次发布更新CHANGELOG、编译两套固件、运行测试、刷新firmware和SHA256SUMS，并记录实物验证范围。
CI只检查发行清单与哈希，不声称远端拥有Keil编译环境。

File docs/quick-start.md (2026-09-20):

# 接线与使用

## 硬件资源

| 功能 | MCU引脚/资源 | 连接说明 |
| --- | --- | --- |
| 灯带 | PB0 / TIM3_CH3 / DMA1通道2 | 经SN74LVC2T45电平转换至LED1_DATA，再接DIN |
| 第二路灯带 | PB1 | 配置保留，本版本不用 |
| 红外 | PA3 / 双边沿EXTI | DYWH-IRM-3638T输出，TIM14测量脉宽 |
| 温度 | PA2 / 开漏GPIO | DS18B20，外部上拉、独立VDD供电 |
| 麦克风 | PA0 / ADC_IN0 | ZTS6216经模拟放大和偏置后输入，TIM1触发8kHz采样 |
| 日志串口 | PB6 TX、PB7 RX | 3.3V串口，115200、8N1，共地 |
| SWD | PA13 SWDIO、PA14 SWCLK | 可额外接NRST；按下载器说明处理参考电压引脚 |
| 电源 | Type-C 5V，板上转3.3V | 灯带使用5V，MCU使用3.3V |

正式固件没有启用实体按键。麦克风ADC输入须保持在允许范围内，不要将5V数字电平接入ADC。
具体元件和接口编号以原理图为准；本表不是PCB端子的物理脚序。

## SWD下载

BOOT0置低；板子可靠供电后连接SWD和GND。使用STM32CubeProgrammer选择ST-LINK，连接、打开HEX、下载并校验，然后复位。
已供电主板不要再接下载器的3.3V电源输出；若端子是VTref电压检测输入，则按下载器说明连接。

## USB DFU下载

1. 使用支持数据的USB线，将BOOT0跳帽接到板上3.3V电源网络。
2. 上电或按复位，使MCU从系统存储器启动。BOOT0不是要求断电时仍有电压。
3. 在STM32CubeProgrammer中选择USB，刷新并连接DFU设备；Windows若未识别，应安装CubeProgrammer附带的DFU驱动。
4. 打开对应HEX并执行下载/校验。HEX含地址，不要按BIN方式重新指定偏移。
5. 将BOOT0恢复到GND，再复位，运行应用程序。

作者调试时曾遇到USB信号悬空及特定USB连接路径兼容性问题，换用拓展坞后连接成功；拓展坞不是本项目的必需硬件。

## 遥控与调试

协议为NEC，地址00 FF。POWER=0x45；1～9依次为0C、18、5E、08、1C、5A、42、52、4A；+=40、-=19、LEFT=07、RIGHT=09。
只有调节键支持长按重复。灵敏度共5档，数字越大越敏感。

9号鼓点门槛目前各档为背景能量×3.0/2.5/2.0/1.5/1.0，再加144/100/64/36/16；滤波、再允许触发和150ms防重复条件还需同时满足。
诊断中的PEAK和TH来自同一个采样块；HIT是窗口触发数，BELOW/RISE/ARM/LOCK是采样块分类数，不是漏掉的鼓点数。

灯不亮先检查DIN方向、5V与共地；有日志无遥控响应时先核对地址和键码；声控无反应时观察BIAS、AMP、CLIP和ERR，再用示波器检查模拟输出。

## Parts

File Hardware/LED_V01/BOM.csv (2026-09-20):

Refs | Value | Footprint | Qty | DNP
C1,C3,C5,C7,C9,C10,C13,C17,C19,C21 | 100nF | Aboka_Passive:C0603 | 10
C2,C4 | 2.2uF | Aboka_Passive:C0805 | 2
C6 | 10uF | Aboka_Passive:C0805 | 1
C8,C15 | 10nF | Aboka_Passive:C0603 | 2
C11,C12,C16 | 1uF | Aboka_Passive:C0603 | 3
C14 | 4.7uF | Aboka_Passive:C0805 | 1
C18 | 100uF 10V | Aboka_Passive:CAP-TH_BD5.0-P2.00-D0.5-FD | 1
CN1 | ZX-SH1.0-7PWT | Aboka_Connector:CONN-SMD_7P-P1.00_MEGASTAR_ZX-SH1.0-7PWT | 1
D1 | SMF6.0A | Aboka_Passive:SOD-123FL_L2.8-W1.9-LS3.7-RD | 1
D2 | USBLC6-2SC6 | Aboka_Discrete:SOT-23-6_L2.9-W1.6-P0.95-LS2.8-BL | 1
D3,D4 | PESD5V0S1BA | Aboka_Discrete:SOD-323_L1.7-W1.3-LS2.5-BI | 2
F1 | Fuse | Fuse:Fuse_1206_3216Metric_Pad1.42x1.75mm_HandSolder | 1
H1 | P= 2.54 | Locator_Connector:HDR-TH_3P-P2.54-V-M_PZ254V-11-03P | 1
MIC1 | ZTS6216 | Aboka_IC:MIC-SMD_4P-L2.8-W1.9-P1.84-TL | 1
R1,R3,R5,R7,R11,R17,R19 | 10K | Aboka_Passive:R0603 | 7
R2,R18 | 1K | Aboka_Passive:R0603 | 2
R4,R10 | 47R | Aboka_Passive:R0603 | 2
R8 | 2K | Aboka_Passive:R0603 | 1
R9,R12 | 47K | Aboka_Passive:R0603 | 2
R13,R14 | 5.1K | Aboka_Passive:R0603 | 2
SW1,SW2 | TS-1088-AR02016 | Aboka_Electromechanical:SW-SMD_L3.9-W3.0-P4.45 | 2
TP1,TP2 | ~ | Aboka_Board:TP= 1.2mm | 2
U1 | DS18B20 | Aboka_IC:TO-92-3_L4.9-W3.7-P1.27-L | 1
U2 | DYWH-IRM-3638T | Aboka_IC:OPTO-TH_3P-L6.0-W5.6-P2.54_TSOP14656 | 1
U3 | TLV9001IDBVR | Aboka_IC:SOT-23-5_L3.0-W1.7-P0.95-LS2.8-BR | 1
U4,U6 | VH3.96-3P ZZ | Aboka_Connector:CONN-TH_3P-P3.96_FWF39601-S03S22W1B | 2
U5 | SN74LVC2T45DCUR | Aboka_IC:VSSOP-8_L2.4-W2.1-P0.50-LS3.2-BR | 1
U7 | TLV75533PDBVR | Aboka_IC:SOT-23-5_L3.0-W1.7-P0.95-LS2.8-BR | 1
U8 | STM32F042G6U6TR | Aboka_IC:UFQFPN-28_L4.0-W4.0-P0.50-BL | 1
USB1 | TYPE-C 16PIN 2MD | Aboka_Connector:USB-C-SMD_TYPE-C-16PIN-2MD-073 | 1

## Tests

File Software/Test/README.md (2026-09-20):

# 基础实验导航

这些工程保留分模块验证过程；最终功能以Official Version中的两套固件为准。实验工程未全部在本次发行中重新上板验证。

| 顺序 | 目录 | 目标和观察方法 |
| --- | --- | --- |
| 1 | 1_Flashing Code | 验证供电、复位和SWD下载链路 |
| 2 | 2_Uart Host | UART接收并原样回显，串口参数以工程配置为准 |
| 3 | 3_Light Led | 验证WS2812B数据时序和输出接线 |
| 4 | 4_Temperature Sensor | DS18B20读取、CRC和串口温度输出 |
| 5 | 5_Micro | ADC采样和串口观察麦克风信号，需模拟电路正常 |
| 6 | 6_IR | NEC学习与查表识别两个工程，输出按键码/名称 |
| 7 | USB DFU | 不需要单独应用工程，操作见根目录docs/quick-start.md |
| 8 | 8_Rainbow Gradient | 单路流动彩虹、led模块化驱动 |
| 9 | 9_Light Led 2 | 修改灯珠数量，测试连接完整性 |

各目录打开MDK-ARM下的uvprojx；驱动路径已改为仓库内ThirdParty。不要把正式版本的灯珠数、引脚或串口参数直接假设为每个实验的配置。
早期阻塞式串口回显只适合基础验证，大量连续输入可能发生接收溢出；正式应用使用独立日志发送机制。
个人原始实验日志、编译日志和调试器会话未收录。

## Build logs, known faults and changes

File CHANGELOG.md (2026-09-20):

# 版本记录

## v0.1.0 — 2026-09-15

- 首次公开原型：STM32F042、WS2812B、红外遥控、温度与麦克风输入。
- 提供67颗和74颗两套布局、9种效果和模块实验导航。
- 工程驱动路径改为仓库相对路径；保留当前鼓点参数。
- 提供KiCad原型、原理图PDF、BOM、DRC报告及两套HEX。
- 作者确认74颗版全部9种模式实物正常；硬件DRC尚未通过，暂无生产用Gerber。

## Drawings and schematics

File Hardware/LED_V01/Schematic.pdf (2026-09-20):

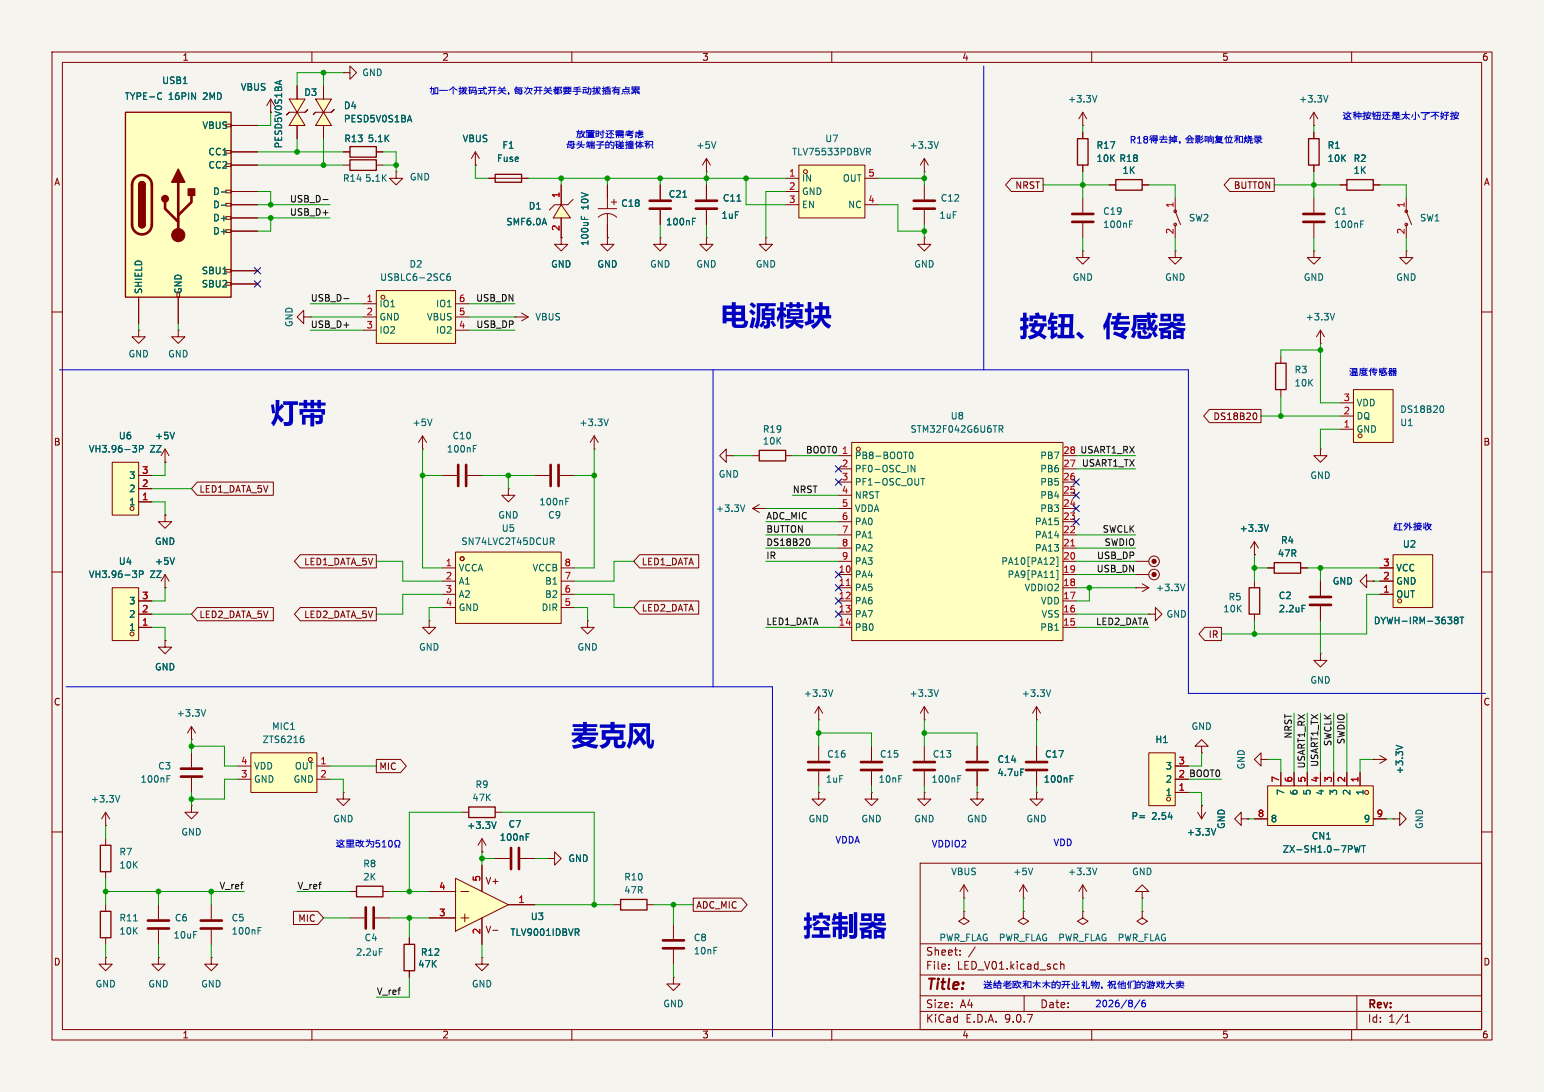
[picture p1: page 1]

þÿR NN*bèx__QsÿkÏk!_Qs•ý‰•bKR¨bÔcÒg p¹}/

þÿn)^¦O aVh VDDA þÿc§R6Vh

Id: 1/1 Title: File: LED_V01.kicad_sch Sheet: / C13

þÿ•~Ù€k'TŒg(g(v„_Ny<riÿy]NÖNìv„n8bY'SV

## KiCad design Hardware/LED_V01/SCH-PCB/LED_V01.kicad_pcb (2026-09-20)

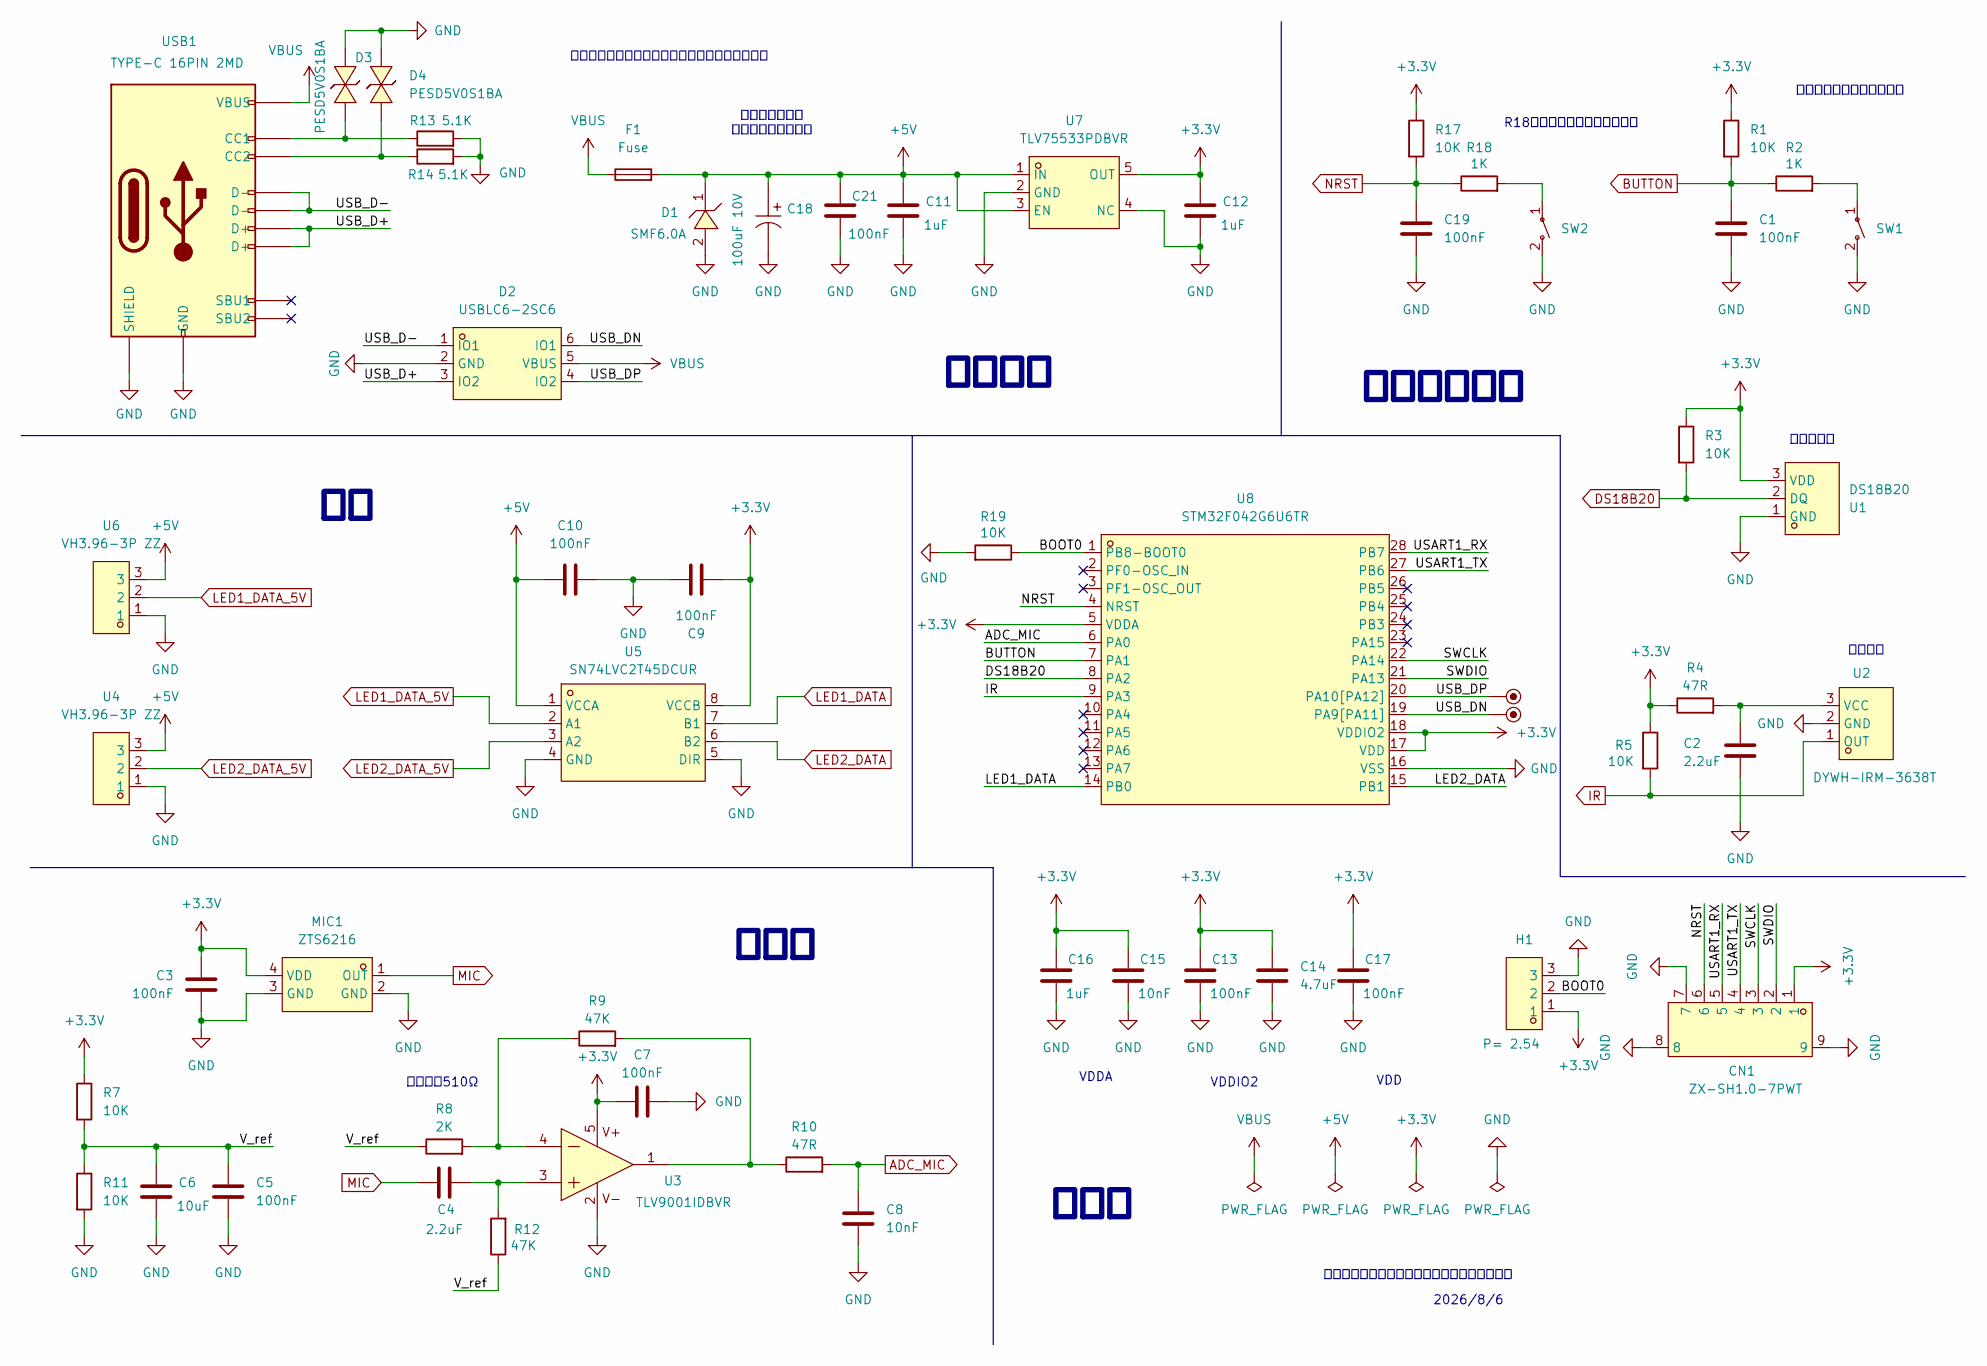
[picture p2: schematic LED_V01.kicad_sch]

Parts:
C1, C3, C5, C7, C9, C10, C13, C17, C19, C21: 100nF; C0603
C2, C4: 2.2uF; C0805
C6: 10uF; C0805
C8, C15: 10nF; C0603
C11, C12, C16: 1uF; C0603
C14: 4.7uF; C0805
C18: 100uF 10V; CAP-TH_BD5.0-P2.00-D0.5-FD; MPN ERA10V100M5X7; LCSC Part C49256785
CN1: ZX-SH1.0-7PWT; CONN-SMD_7P-P1.00_MEGASTAR_ZX-SH1.0-7PWT; MPN ZX-SH1.0-7PWT; LCSC Part C7430449
D1: SMF6.0A; SOD-123FL_L2.8-W1.9-LS3.7-RD; MPN SMF6.0A; LCSC Part C2857264
D2: USBLC6-2SC6; SOT-23-6_L2.9-W1.6-P0.95-LS2.8-BL; MPN USBLC6-2SC6; LCSC Part C2827654
D3, D4: PESD5V0S1BA; SOD-323_L1.7-W1.3-LS2.5-BI; MPN PESD5V0S1BA; LCSC Part C5158048
F1: Fuse; Fuse_1206_3216Metric_Pad1.42x1.75mm_HandSolder; LCSC Part C135343
H1: P= 2.54; HDR-TH_3P-P2.54-V-M_PZ254V-11-03P; MPN PZ254V-11-03P; LCSC Part C2937625
MIC1: ZTS6216; MIC-SMD_4P-L2.8-W1.9-P1.84-TL; MPN ZTS6216; LCSC Part C481302
R1, R3, R5, R7, R11, R17, R19: 10K; R0603
R2, R18: 1K; R0603
R4, R10: 47R; R0603
R8: 2K; R0603
R9, R12: 47K; R0603
R13, R14: 5.1K; R0603
SW1, SW2: TS-1088-AR02016; SW-SMD_L3.9-W3.0-P4.45; MPN TS-1088-AR02016; LCSC Part C720477
TP1, TP2: TP= 1.2mm
U1: DS18B20; TO-92-3_L4.9-W3.7-P1.27-L; MPN DS18B20(UMW); LCSC Part C376006
U2: DYWH-IRM-3638T; OPTO-TH_3P-L6.0-W5.6-P2.54_TSOP14656; MPN DYWH-IRM-3638T; LCSC Part C52125019
U3: TLV9001IDBVR; SOT-23-5_L3.0-W1.7-P0.95-LS2.8-BR; MPN TLV9001IDBVR; LCSC Part C398363
U4, U6: VH3.96-3P ZZ; CONN-TH_3P-P3.96_FWF39601-S03S22W1B; MPN VH3.96-3P ZZ; LCSC Part C5379869
U5: SN74LVC2T45DCUR; VSSOP-8_L2.4-W2.1-P0.50-LS3.2-BR; MPN SN74LVC2T45DCUR; LCSC Part C15741
U7: TLV75533PDBVR; SOT-23-5_L3.0-W1.7-P0.95-LS2.8-BR; MPN TLV75533PDBVR; LCSC Part C404027
U8: STM32F042G6U6TR; UFQFPN-28_L4.0-W4.0-P0.50-BL; MPN STM32F042G6U6TR; LCSC Part C2971720
USB1: TYPE-C 16PIN 2MD; USB-C-SMD_TYPE-C-16PIN-2MD-073; MPN TYPE-C 16PIN 2MD(073); LCSC Part C2765186

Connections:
+3.3V: C3.1, C7.1, C9.1, C12.1, C13.1, C14.1, C15.1, C16.1, C17.1, CN1.1, H1.1, MIC1.4 (VDD), R1.2, R3.2, R4.2, R5.2, R7.2, R17.2, U1.3 (VDD), U3.5 (V+), U5.8 (VCCB), U7.5 (OUT), U8.5 (VDDA), U8.17 (VDD), U8.18 (VDDIO2)
+5V: C10.1, C11.1, C18.1, C21.1, D1.1 (C), F1.2, U4.3, U5.1 (VCCA), U6.3, U7.1 (IN), U7.3 (EN)
/BOOT0: H1.2, R19.2, U8.1 (PB8-BOOT0)
/SWCLK: CN1.3, U8.22 (PA14)
/SWDIO: CN1.2, U8.21 (PA13)
/USART1_RX: CN1.5, U8.28 (PB7)
/USART1_TX: CN1.4, U8.27 (PB6)
/USB_D+: D2.3 (IO2), USB1.A6 (D+), USB1.B6 (D+)
/USB_D-: D2.1 (IO1), USB1.A7 (D-), USB1.B7 (D-)
/USB_DN: D2.6 (IO1), TP2.1, U8.19 (PA9[PA11])
/USB_DP: D2.4 (IO2), TP1.1, U8.20 (PA10[PA12])
/V_ref: C5.1, C6.1, R7.1, R8.2, R11.2, R12.2
ADC_MIC: C8.1, R10.1, U8.6 (PA0)
BUTTON: C1.1, R1.1, R2.2, U8.7 (PA1)
DS18B20: R3.1, U1.2 (DQ), U8.8 (PA2)
GND: C1.2, C2.2, C3.2, C5.2, C6.2, C7.2, C8.2, C9.2, C10.2, C11.2, C12.2, C13.2, C14.2, C15.2, C16.2, C17.2, C18.2, C19.2, C21.2, CN1.7, CN1.8, CN1.9, D1.2 (A), D2.2 (GND), D3.2, D4.2, H1.3, MIC1.2 (GND), MIC1.3 (GND), R11.1, R13.1, R14.1, R19.1, SW1.2, SW2.2, U1.1 (GND), U2.2 (GND), U3.2 (V-), U4.1, U5.4 (GND), U5.5 (DIR), U6.1, U7.2 (GND), U7.4 (NC), U8.16 (VSS), USB1.13 (SHIELD), USB1.14 (SHIELD), USB1.A1B12 (GND), USB1.B1A12 (GND)
IR: R5.1, U2.1 (OUT), U8.9 (PA3)
LED1_DATA: U5.7 (B1), U8.14 (PB0)
LED1_DATA_5V: U5.2 (A1), U6.2
LED2_DATA: U5.6 (B2), U8.15 (PB1)
LED2_DATA_5V: U4.2, U5.3 (A2)
MIC: C4.1, MIC1.1 (OUT)
NRST: C19.1, CN1.6, R17.1, R18.2, U8.4 (NRST)
unnamed: R2.1, SW1.1
unnamed: R18.1, SW2.1
unnamed: C2.1, R4.1, U2.3 (VCC)
unnamed: C4.2, R12.1, U3.3 (IN+)
unnamed: R8.1, R9.2, U3.4 (IN-)
unnamed: R9.1, R10.2, U3.1 (OUT)
unnamed: D3.1, R13.2, USB1.A5 (CC1)
unnamed: D4.1, R14.2, USB1.B5 (CC2)
VBUS: D2.5 (VBUS), F1.1, USB1.A4B9 (VBUS), USB1.B4A9 (VBUS)

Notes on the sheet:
VDDA
VDDIO2
麦克风
加一个拨码式开关，每次开关都要手动拔插有点累
控制器
放置时还需考虑 母头端子的碰撞体积
电源模块
温度传感器
R18得去掉，会影响复位和烧录
2026/8/6
这里改为510Ω
按钮、传感器
送给老欧和木木的开业礼物，祝他们的游戏大卖
这种按钮还是太小了不好按
VDD
红外接收

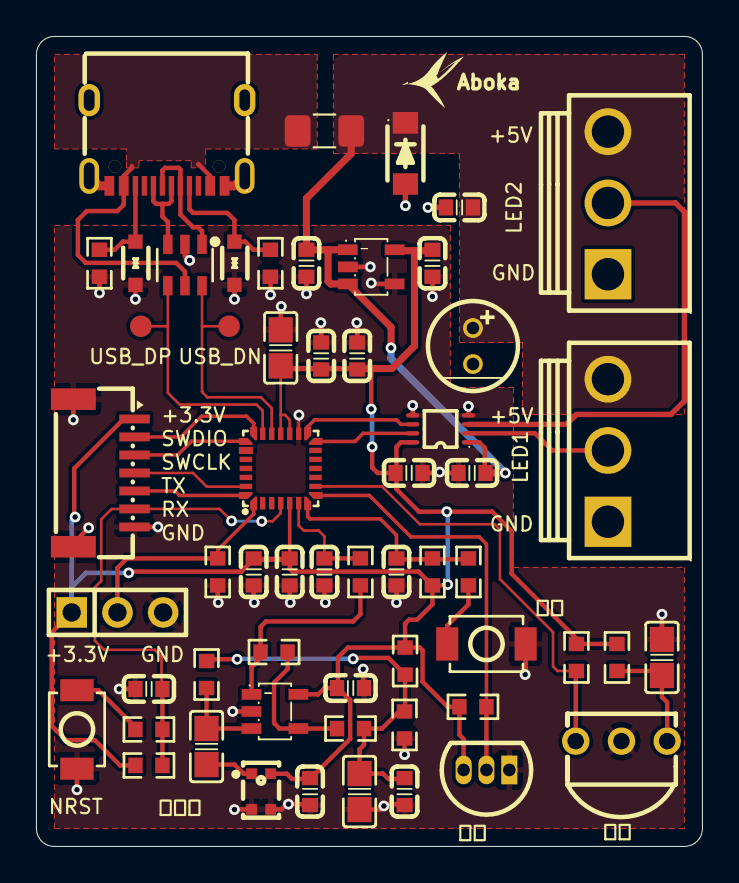
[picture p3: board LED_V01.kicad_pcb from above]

Board: 2 copper layers, 37.0 x 45.0 mm, 57 parts (0 on the bottom side), 32 nets.

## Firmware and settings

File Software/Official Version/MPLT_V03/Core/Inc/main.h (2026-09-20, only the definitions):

#define Key_Pin GPIO_PIN_1
#define Key_GPIO_Port GPIOA
#define DS18B20_DQ_Pin GPIO_PIN_2
#define DS18B20_DQ_GPIO_Port GPIOA

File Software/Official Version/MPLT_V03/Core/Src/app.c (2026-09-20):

#include "app.h"
#include "effects.h"
#include "ir.h"
#include "debug_log.h"
#include "main.h"
#include "temperature.h"
#include "audio.h"
#include "beat.h"

static LED_Color pixels[LED_COUNT];
static uint8_t power_on, mode, brightness, speed, dirty;
static uint8_t sensitivity;
static uint32_t frame_at, pressed_at, adjusted_at, diagnostics_at;
static uint32_t led_errors_seen, ir_errors_seen;
static uint8_t beat_log_pending;
static const uint8_t mode_keys[9] = {0x0C,0x18,0x5E,0x08,0x1C,0x5A,0x42,0x52,0x4A};

static void Status(void)
{
    Log_Text(power_on ? "STATE ON MODE=" : "STATE OFF MODE=");
    Log_Number(mode);
    Log_Text(" BRIGHTNESS="); Log_Number(brightness);
    Log_Text("% SPEED="); Log_Number(speed+1U);
    Log_Text(" SENS="); Log_Number(sensitivity+1U);
    Log_Text("\r\n");
}

static void HandleKey(const IR_Event *e)
{
    uint8_t i;
    uint8_t adjust = e->code == 0x40U || e->code == 0x19U ||
                     e->code == 0x07U || e->code == 0x09U;
    if (e->repeat)
    {
        /* 长按仅允许调整键；首次等待 350 ms，之后至少间隔 160 ms。 */
        if (!adjust || !power_on || e->time_ms-pressed_at < 350U ||
            e->time_ms-adjusted_at < 160U) return;
    }
    else pressed_at = e->time_ms;

    Log_Text(e->repeat ? "REPEAT " : "KEY ");
    Log_Text(IR_KeyName(e->code));
    Log_Text(" 0x"); Log_Hex8(e->code); Log_Text("\r\n");
    if (e->code == 0x45U)
    {
        power_on = !power_on;
        frame_at = HAL_GetTick();
        dirty = 1U;
        Status();
        return;
    }
    /* 关灯时不会修改模式或参数；只有 POWER 可以唤醒。 */
    if (!power_on) { Log_Text("IGNORED: OFF\r\n"); return; }
    for (i = 0U; i < sizeof(mode_keys)/sizeof(mode_keys[0]); i++)
    {
        if (e->code == mode_keys[i])
        {
            mode = i+1U;
            Effects_Reset();
            frame_at = HAL_GetTick();
            dirty = 1U;
            Status();
            return;
        }
    }
    if (adjust)
    {
        adjusted_at = e->time_ms;
        if (e->code == 0x40U && brightness < LED_MAX_BRIGHTNESS) brightness += 3U;
        if (e->code == 0x19U && brightness > 3U) brightness -= 3U;
        if (mode == 8U || mode == 9U)
        {
            if (e->code == 0x07U && sensitivity > 0U) sensitivity--;
            if (e->code == 0x09U && sensitivity < 4U) sensitivity++;
            Audio_SetSensitivity(sensitivity);
        }
        else
        {
            if (e->code == 0x07U && speed > 0U) speed--;
            if (e->code == 0x09U && speed < 4U) speed++;
        }
        dirty = 1U;
        Status();
    }
    else Log_Text("UNASSIGNED IN V03\r\n");
}

void App_Init(void)
{
    power_on = 1U; mode = 3U; brightness = 15U; speed = 2U; dirty = 1U;
    sensitivity = 2U;
    frame_at = HAL_GetTick();
    LED_Init();
    Effects_Reset();
    IR_Init();
    /* TIM14 已由 IR_Init 启动，温度模块不能重复清零它。 */
    Temperature_Init();
    Audio_Init();
    Audio_SetSensitivity(sensitivity);
    Log_Text("MPLT V03 READY; 67 LEDs; NEC user=00 FF\r\n");
    Status();
}

static void TemperatureLog(void)
{
    static const char *const names[] = {
        "WAITING", "OK", "NO_DEVICE", "CRC_ERROR", "BAD_DATA", "NOT_READY"
    };
    int32_t raw = Temperature_LatestRaw();
    uint32_t magnitude, fraction;
    Log_Text("TEMP "); Log_Text(names[Temperature_GetStatus()]);
    if (Temperature_HasSample())
    {
        Log_Text(" LAST=");
        if (raw < 0) Log_Text("-");
        magnitude = (uint32_t)(raw < 0 ? -raw : raw);
        Log_Number(magnitude/16U); Log_Text(".");
        fraction = (magnitude%16U)*100U/16U;
        if (fraction < 10U) Log_Text("0");
        Log_Number(fraction); Log_Text("C");
    }
    Log_Text(" SAMPLES="); Log_Number(Temperature_SampleCount());
    if (Temperature_IsFault()) Log_Text(" FAULT");
    Log_Text("\r\n");
}

static void BeatLog(void)
{
    Beat_Diagnostics d;
    Beat_TakeDiagnostics(&d);
    Log_Text("BEAT WIN VALID="); Log_Number(d.valid);
    Log_Text(" PEAK="); Log_Number(d.peak);
    Log_Text(" TH="); Log_Number(d.threshold);
    Log_Text(" BG="); Log_Number(d.background);
    Log_Text(" SENS="); Log_Number(d.sensitivity);
    Log_Text(" HIT="); Log_Number(d.results[BEAT_HIT]);
    Log_Text(" BELOW="); Log_Number(d.results[BEAT_BELOW]);
    Log_Text(" RISE="); Log_Number(d.results[BEAT_NO_RISE]);
    Log_Text(" ARM="); Log_Number(d.results[BEAT_NOT_ARMED]);
    Log_Text(" LOCK="); Log_Number(d.results[BEAT_LOCKED]);
    Log_Text("\r\n");
}

static void AudioLog(void)
{
    static const char *const names[] = {"WAITING", "OK", "FAULT"};
    Log_Text("AUDIO "); Log_Text(names[Audio_GetStatus()]);
    Log_Text(" AMP="); Log_Number(Audio_GetAmplitude());
    Log_Text(" LEVEL="); Log_Number(Audio_GetLevel());
    Log_Text(" LEVEL9="); Log_Number(Audio_GetPulseLevel());
    Log_Text(" LOW="); Log_Number(Beat_Energy());
    Log_Text(" BG="); Log_Number(Beat_Background());
    Log_Text(" BEATS="); Log_Number(Beat_Count());
    Log_Text(" BIAS="); Log_Number(Audio_GetBias());
    Log_Text(" CLIP="); Log_Number(Audio_GetClippedSamples());
    Log_Text(" ERR="); Log_Number(Audio_GetErrorCount());
    Log_Text(" BLOCKS="); Log_Number(Audio_GetBlockCount());
    Log_Text("\r\n");
}

void App_Task(void)
{
    IR_Event event;
    uint32_t now, elapsed, errors;
    uint8_t ready;
    Log_Task();
    while (IR_Poll(&event)) HandleKey(&event);
    Audio_Task();
    /* 等待转换期间立即返回；关灯及其他模式下也持续更新温度。 */
    Temperature_Task();
    now = HAL_GetTick();
    ready = LED_Ready();
    errors = LED_ErrorCount();
    if (errors != led_errors_seen)
    {
        led_errors_seen = errors;
        dirty = 1U;
        Log_Text("LED DMA ERROR count="); Log_Number(errors); Log_Text("\r\n");
    }
    /* 50 帧/秒刷新。黑帧发送成功前一直保持 dirty，绝不遗漏关灯。 */
    if (ready && (dirty || (power_on && now-frame_at >= 20U)))
    {
        elapsed = now-frame_at;
        if (elapsed > 100U) elapsed = 100U;
        if (power_on) Effects_Render(mode, speed, elapsed, pixels);
        if (LED_Show(pixels, power_on ? brightness : 0U))
        {
            dirty = 0U;
            frame_at = now;
        }
    }
    /* 噪声和坏帧只累计诊断，每秒最多汇报一次，避免刷屏。 */
    if (now-diagnostics_at >= 1000U)
    {
        diagnostics_at = now;
        beat_log_pending = 1U;
        TemperatureLog();
        AudioLog();
        errors = IR_ErrorCount();
        if (errors != ir_errors_seen)
        {
            ir_errors_seen = errors;
            Log_Text("IR INVALID/OVERFLOW count=");
            Log_Number(errors); Log_Text("\r\n");
        }
    }
    /* 错开半秒输出，避免温度、音频和鼓点诊断同时挤满256字节缓冲。 */
    if (beat_log_pending && now-diagnostics_at >= 500U)
    {
        beat_log_pending = 0U;
        BeatLog();
    }
    Log_Task();
}

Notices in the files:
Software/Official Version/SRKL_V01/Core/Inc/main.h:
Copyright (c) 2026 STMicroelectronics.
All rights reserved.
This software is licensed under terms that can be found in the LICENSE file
